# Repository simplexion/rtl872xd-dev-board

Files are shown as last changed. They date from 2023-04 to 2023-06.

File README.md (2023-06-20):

# RTL872xD Development Board
Development board(s) for the Realtek [RTL872xD](https://www.realtek.com/en/products/communications-network-ics/item/rtl8721dm) dual band WLAN and BLE MCU.
Please view the [product page](https://www.realmcu.com/en/Home/Product/a6248c82-7c9a-4f79-bebf-0df240726c4d) for detailed information and documentation.

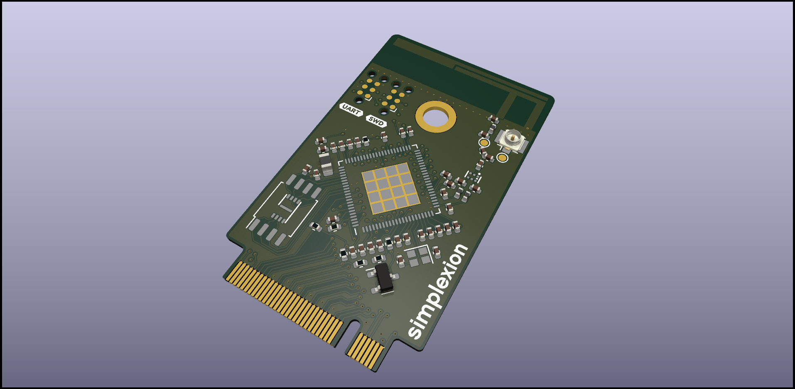
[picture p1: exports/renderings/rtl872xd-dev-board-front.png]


Browse the files on [KiCanvas](https://kicanvas.org/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) - by [Stargirl Flowers](https://github.com/theacodes)

## Directory Structure
| directory  | content |
|---|---|
| source | KiCad project directories |
| production | fabrication files (Gerber, BOM, placement) |
| exports | schematic and layout plots, board 3D model and renderings |
| datasheets | component datasheets |
| assets | board setups, component 3D models, logos |
| scripts | BOM export plugins, miscellaneous helper scripts for file conversion |
| hooks | git hooks, for example for automatic documentation export |

## Automation
This repository contains a Makefile that automates PDF and Gerber export.

### Requirements
Apart from [KiCad 7](#kicad-version) this requires some additional software.

The Makefile calls a Python script that makes use of [sexptdata](https://pypi.org/project/sexpdata/) to parse KiCad files.
Install [Poetry](https://python-poetry.org/) and run `poetry shell` followed by `poetry install` in the root of this repositoryto set up a virtual environment with the required package(s). To re-enter this environment, simply run `poetry shell` in the root of this repository.

For PDF export you additonally need to install [Poppler](https://poppler.freedesktop.org/).
Gerber export requires [zip](https://infozip.sourceforge.net/).

#### Nix(OS)
If you are using the Nix package manager, you can enter a development environment
with KiCad and all other software by running `nix-shell` in the root of this
repository.

### Export
To export all PDFs and production files, simply run
```shell
make
```
PDFs and production files are exported automatically when you `git commit`, if you have
[Git Hooks](#installing-git-hooks-optional) set up.

### Installing Git Hooks (optional)
The [hooks](hooks) directory contains client-side [git hooks](https://git-scm.com/book/en/v2/Customizing-Git-Git-Hooks).
Currently only the pre-commit hook is used to automatically export plots.

To enable the hooks locally, run the following in the root of the repository.
```shell
git config core.hooksPath ./hooks
```

## KiCad Version
Version information of the KiCad used to generate the files.
```
[nix-shell:~/repos/kicad-template]$ kicad-cli version --format about

Application: kicad-cli x86_64 on x86_64

Version: 7.0.1, release build

Libraries:
        wxWidgets 3.2.2
        FreeType 2.12.1
        HarfBuzz 6.0.0
        FontConfig 2.14.0
        libcurl/7.87.0 OpenSSL/3.0.8 zlib/1.2.13 brotli/1.0.9 zstd/1.5.2 libidn2/2.3.2 libssh2/1.10.0 nghttp2/1.51.0

Platform: , 64 bit, Little endian, wxBase, , wayland

Build Info:
        Date: Jan  1 1980 00:00:00
        wxWidgets: 3.2.2 (wchar_t,wx containers) GTK+ 0.0
        Boost: 1.79.0
        OCC: 7.6.2
        Curl: 7.87.0
        ngspice: 37
        Compiler: GCC 12.2.0 with C++ ABI 1017

Build settings:
        KICAD_USE_EGL=ON
        KICAD_SPICE=ON
```

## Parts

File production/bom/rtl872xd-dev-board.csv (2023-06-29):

Designator | Footprint | Quantity | Value | LCSC Part #
R3,R2 | Resistor_SMD:R_0402_1005Metric | 2 | 10k | C25744
R5 | Resistor_SMD:R_0402_1005Metric | 1 | 12k | C25752
J2 | Connector_M.2:M.2-B-KEY-22x | 1 | Bus_M.2_Socket_B
TP3,TP4,TP9,TP5,TP6,TP7,TP8 | TestPoint:TestPoint_Pad_D1.0mm | 7 | TestPoint
J3,J4 | Connector:Tag-Connect_TC2030-IDC-NL_2x03_P1.27mm_Vertical | 2 | Conn_ARM_SWD_TagConnect_TC2030-NL
C10,C17,C19,C20,C21,C22,C23,C24,C25,C26,C27,C28,C30,C32 | Capacitor_SMD:C_0402_1005Metric | 14 | 100n | C1525
U2 | Package_SO:SOIC-8_5.23x5.23mm_P1.27mm | 1 | W25Q128JVS | C97521
C13,C36 | Capacitor_SMD:C_0402_1005Metric | 2 | 1u | C52923
C14 | Capacitor_SMD:C_0402_1005Metric | 1 | 4.7n | C1538
C15,C29,C34,C35 | Capacitor_SMD:C_0402_1005Metric | 4 | 2.2u | C12530
C16 | Capacitor_SMD:C_0402_1005Metric | 1 | 10u | C15525
C18 | Capacitor_SMD:C_0402_1005Metric | 1 | 1n | C1523
C31 | Capacitor_SMD:C_0402_1005Metric | 1 | 4.7u | C23733
L4 | Inductor_SMD:L_0805_2012Metric | 1 | 2.2u | C1043
R6 | Resistor_SMD:R_0402_1005Metric | 1 | 200 | C25087
R7 | Resistor_SMD:R_0402_1005Metric | 1 | 1k | C25744
U4 | Package_TO_SOT_SMD:SOT-23 | 1 | LM809 | C526393
Y1 | Crystal:Crystal_SMD_2016-4Pin_2.0x1.6mm | 1 | 40MHz | C516561
AE1 | RF_Antenna_project:AKK_2.4GHz_5GHz_Left | 1 | Antenna_Shield
C1 | Capacitor_SMD:C_0402_1005Metric | 1 | 0.4p | C387964
C2 | Capacitor_SMD:C_0402_1005Metric | 1 | 0.3p | C610035
C3 | Capacitor_SMD:C_0402_1005Metric | 1 | 0.5p | C152789
C4 | Capacitor_SMD:C_0402_1005Metric | 1 | 1.0p | C1550
C5,C6 | Capacitor_SMD:C_0402_1005Metric | 2 | 0R | C17168
DP1 | RF_Diplexer:DP_0603_1608Metric | 1 | MDPX18M1524P69-D03 | C486317
J1 | Connector_Coaxial:U.FL_Hirose_U.FL-R-SMT-1_Vertical | 1 | Conn_Coaxial | C4749207
L1 | Inductor_SMD:L_0402_1005Metric | 1 | 1n | C74299
L2 | Inductor_SMD:L_0402_1005Metric | 1 | 3.3n | C280259
L3 | Inductor_SMD:L_0402_1005Metric | 1 | 1n(0.9n) | C74299
TP1,TP2 | TestPoint:TestPoint_Pad_D1.0mm | 2 | TestPoint

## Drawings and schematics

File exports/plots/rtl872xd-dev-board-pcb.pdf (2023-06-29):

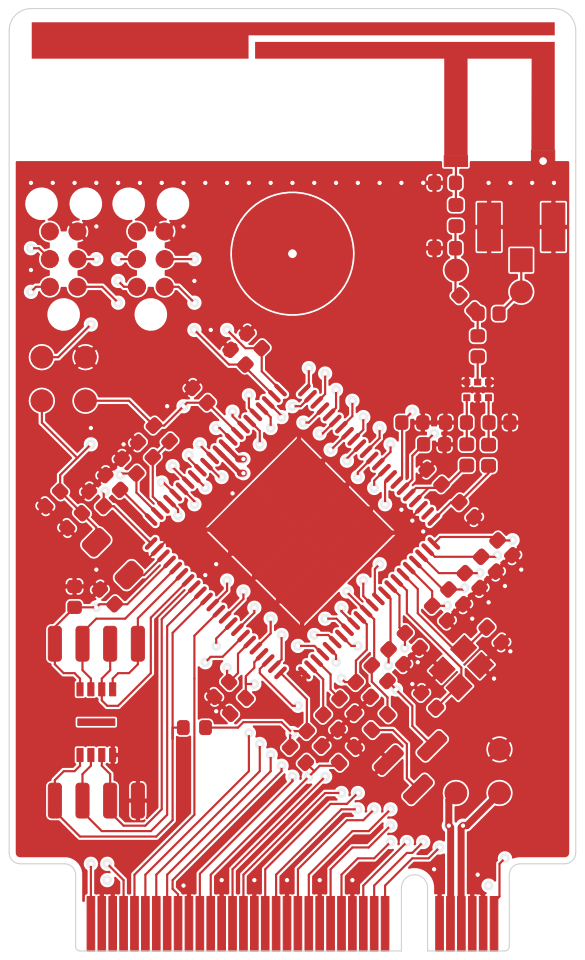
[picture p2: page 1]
D Date: KiCad; kicad-cli; 7.0.1 Size: A4; Rev: 0.1.0; author:; Markus "marble"; Blechschmidt pid: TBD

File: rtl872xd-dev-board.kicad_pcb Sheet: Simplexion GmbH

Id: 1/1 Title: RTL872xD Development Board

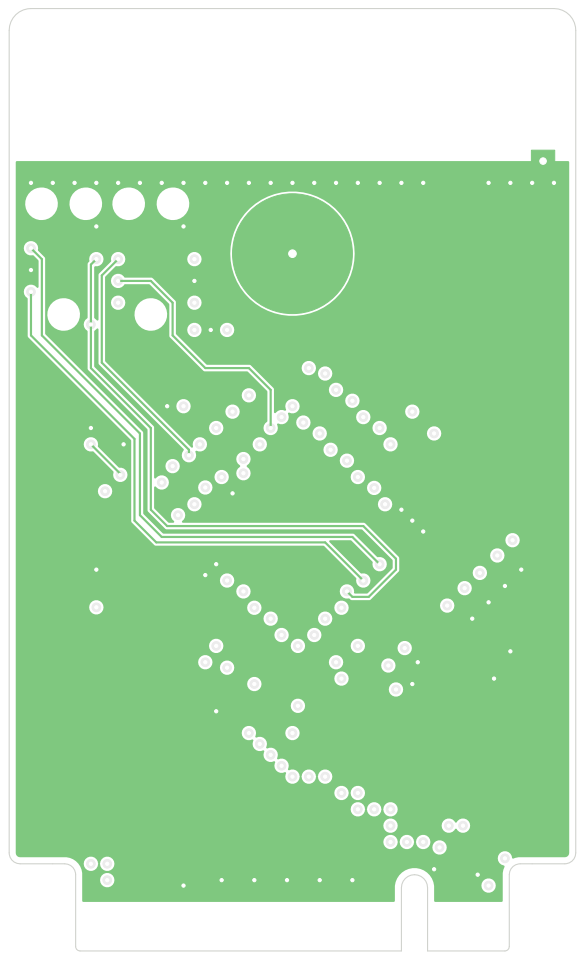
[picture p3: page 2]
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

File: rtl872xd-dev-board.kicad_pcb Sheet: Simplexion GmbH

Id: 1/1 Title: RTL872xD Development Board

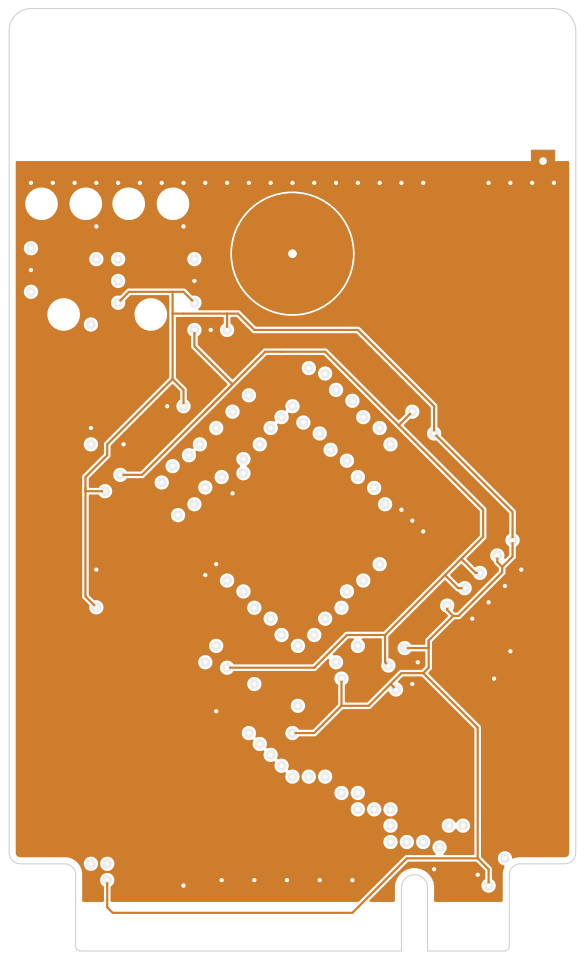
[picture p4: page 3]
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

File: rtl872xd-dev-board.kicad_pcb Sheet: Simplexion GmbH

Id: 1/1 Title: RTL872xD Development Board

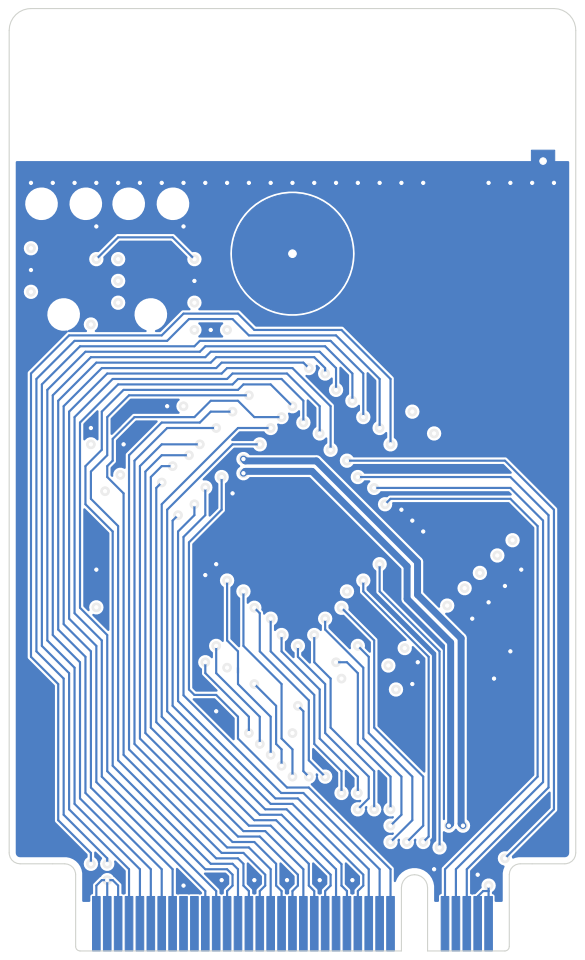
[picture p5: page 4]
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

File: rtl872xd-dev-board.kicad_pcb Sheet: Simplexion GmbH

Id: 1/1 Title: RTL872xD Development Board

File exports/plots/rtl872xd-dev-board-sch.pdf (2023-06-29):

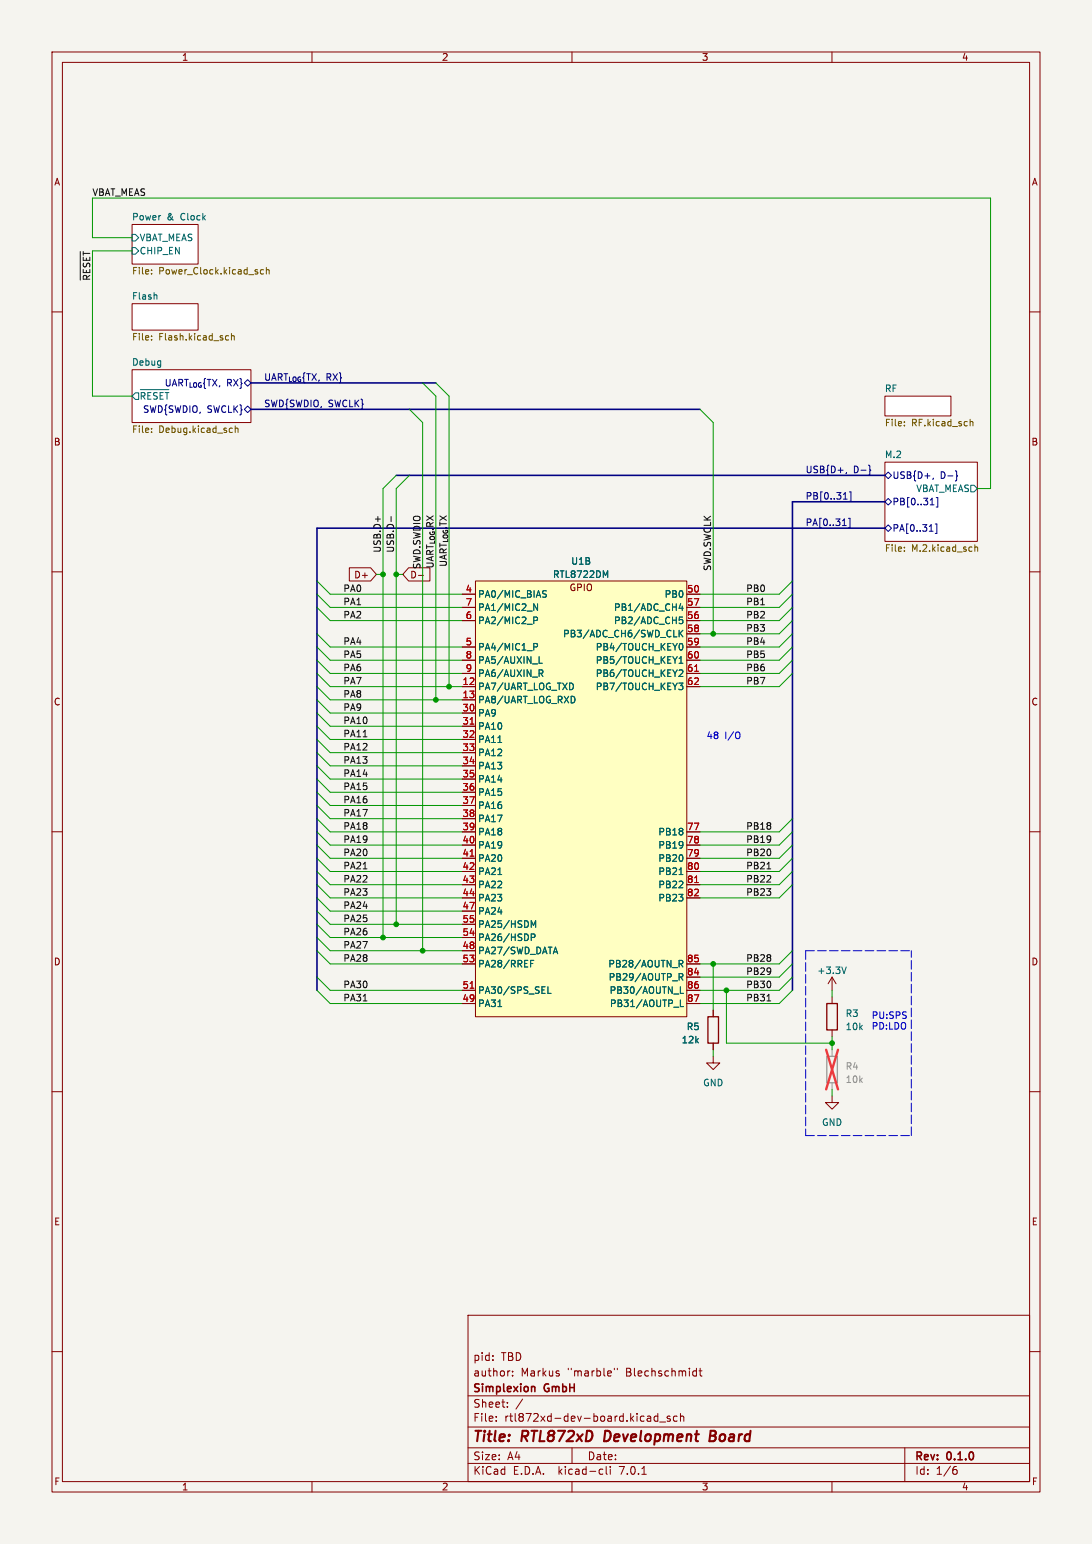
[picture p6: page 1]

USB{D+, D-} VBAT_MEAS M.2 File: M.2.kicad_sch Flash File: Flash.kicad_sch UART_{LOG}{TX, RX}

File: rtl872xd-dev-board.kicad_sch Sheet: / Simplexion GmbH

Id: 1/6 Title: RTL872xD Development Board

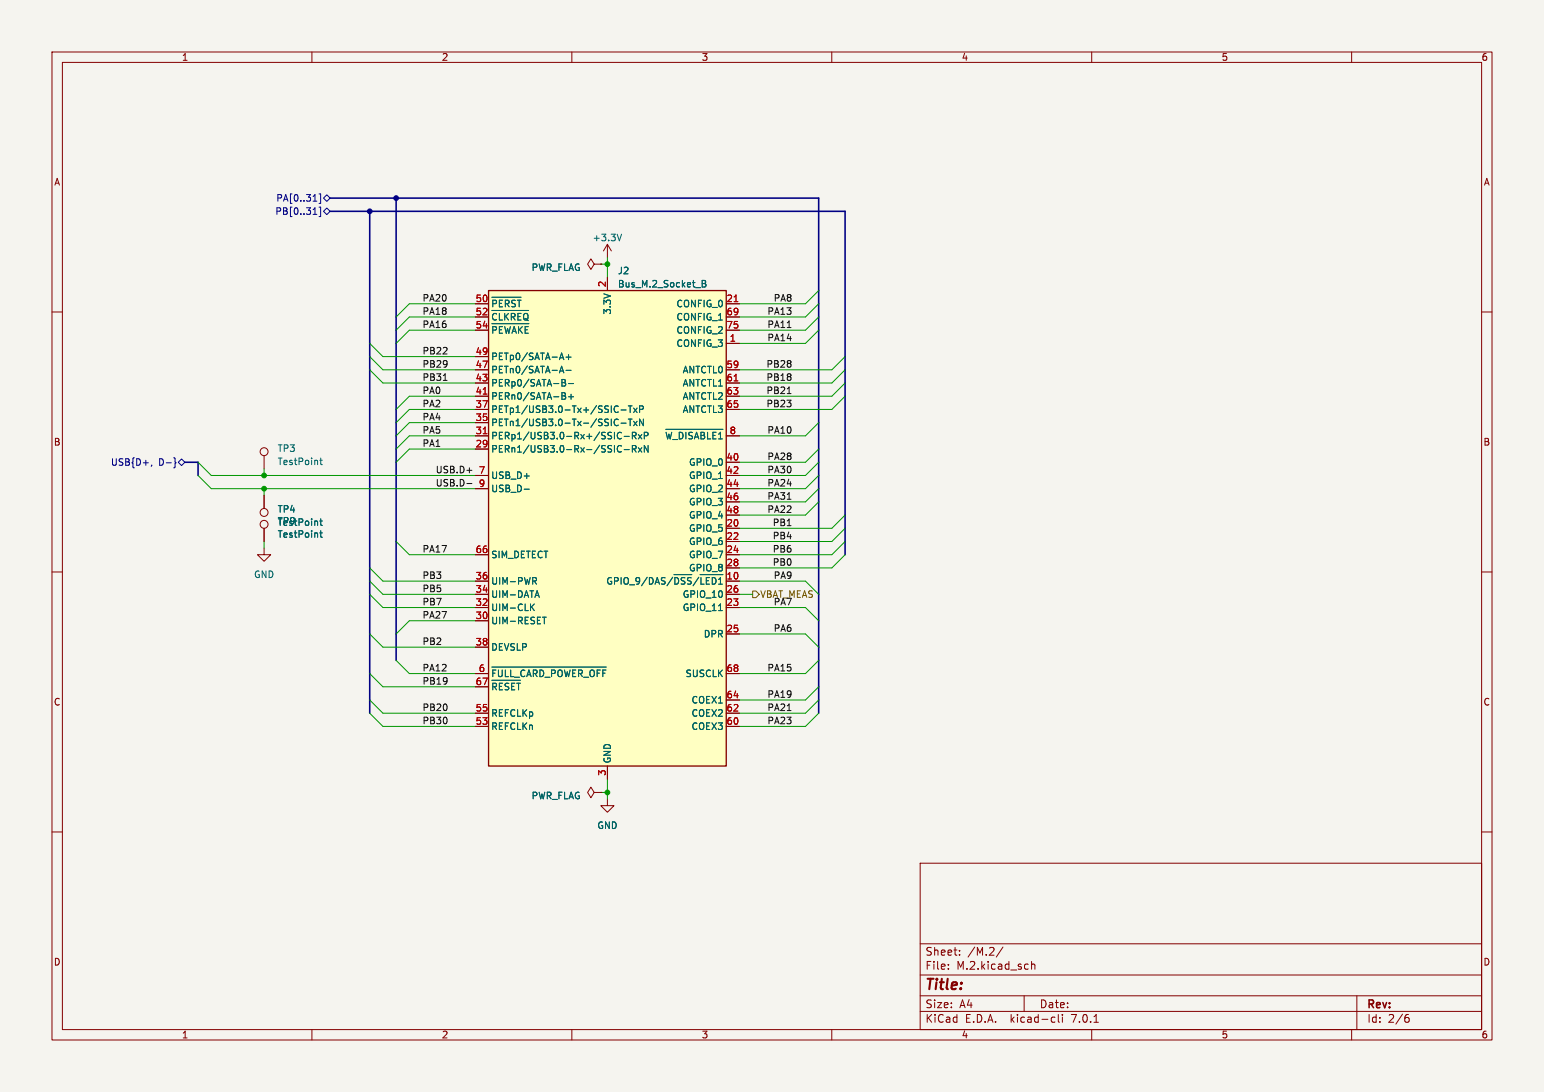
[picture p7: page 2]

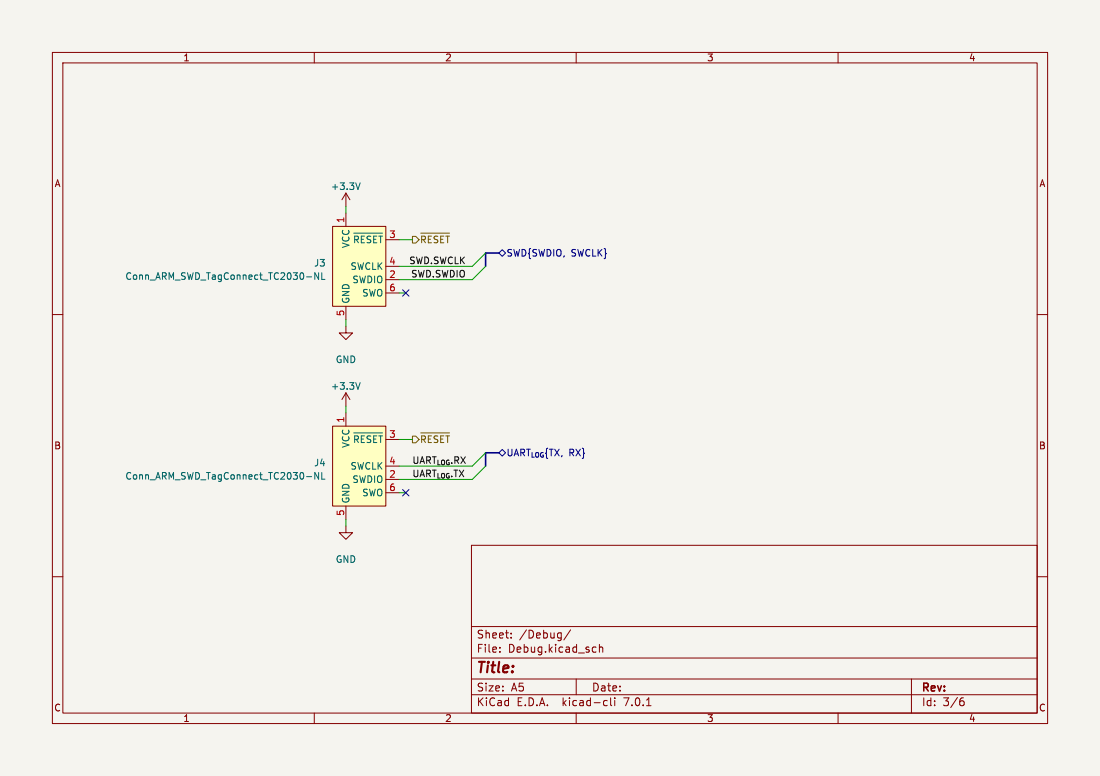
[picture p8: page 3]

1 SWDIO 2 ~{RESET}3 SWCLK 4 GND

~{RESET}
UART_{LOG}{TX, RX} UART_{LOG}.RX
UART_{LOG}.TX

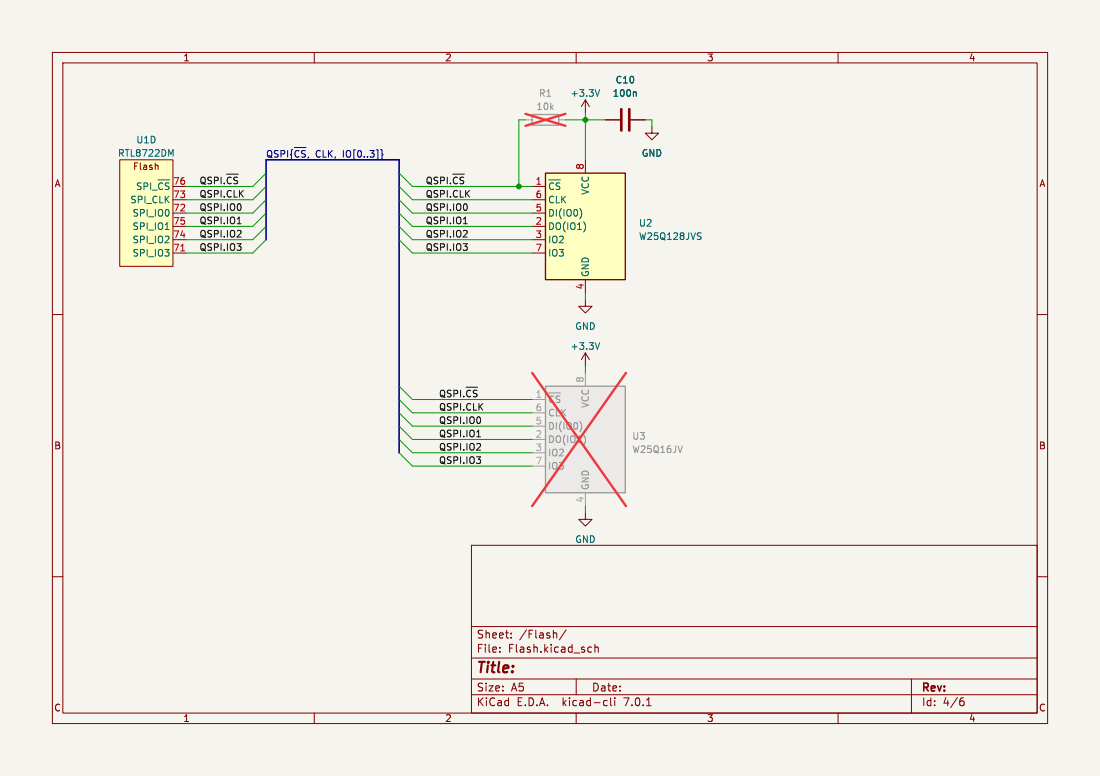
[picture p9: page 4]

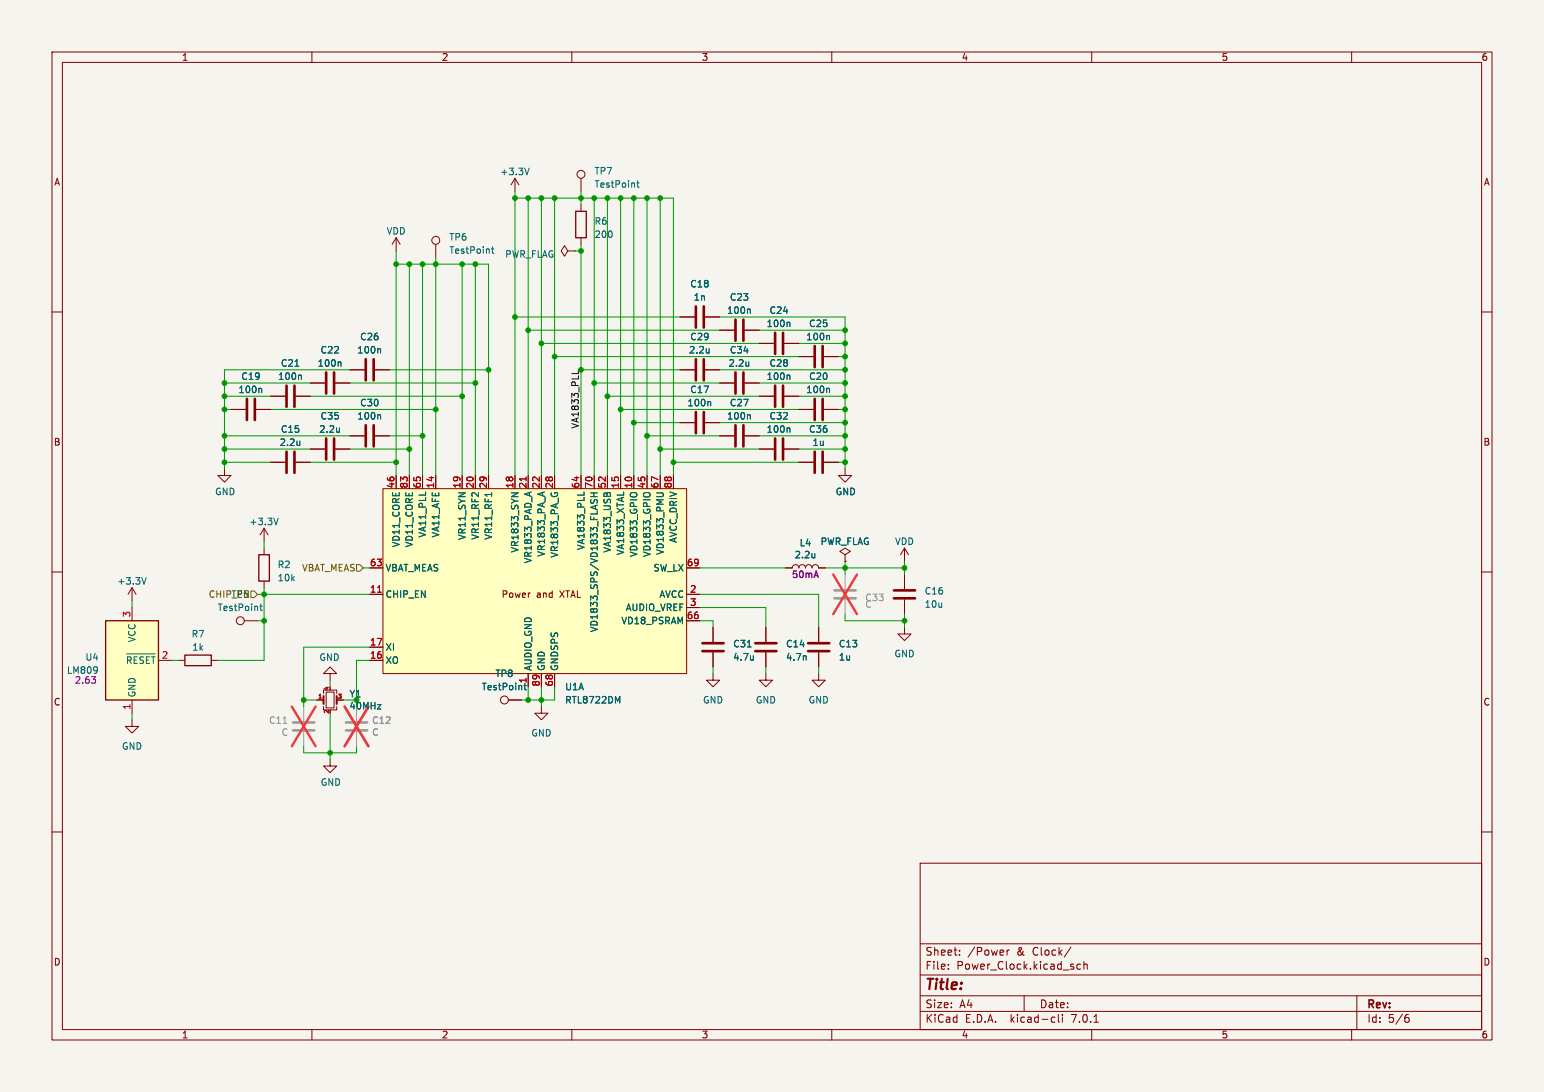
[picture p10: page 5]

1 VD1833_GPIO 10 VA11_AFE 14 VA1833_XTAL 15 XO 16 XI 17 VR1833_SYN 18 VR11_SYN 19 AVCC 2 VR11_RF2 20 VR1833_PAD_A 21 VR1833_PA_A 22 VR1833_PA_G 28 VR11_RF1 29 AUDIO_VREF 3 VD1833_GPIO 45 VD11_CORE 46 VA1833_USB 52 VBAT_MEAS 63 VA1833_PLL 64 VA11_PLL 65 VD18_PSRAM 66 VD1833_PMU 67 GNDSPS 68 SW_LX 69 VD1833_SPS/VD1833_FLASH 70 VD11_CORE 83 AVCC_DRIV 88 GND 89 U1A RTL8722DM

1 VD1833_GPIO 10 VA11_AFE 14 VA1833_XTAL 15 XO 16 XI 17 VR1833_SYN 18 VR11_SYN 19 AVCC 2 VR11_RF2 20 VR1833_PAD_A 21 VR1833_PA_A 22 VR1833_PA_G 28 VR11_RF1 29 AUDIO_VREF 3 VD1833_GPIO 45 VD11_CORE 46 VA1833_USB 52 VBAT_MEAS 63 VA1833_PLL 64 VA11_PLL 65 VD18_PSRAM 66 VD1833_PMU 67 GNDSPS 68 SW_LX 69 VD1833_SPS/VD1833_FLASH 70 VD11_CORE 83 AVCC_DRIV 88 GND 89 C12 C

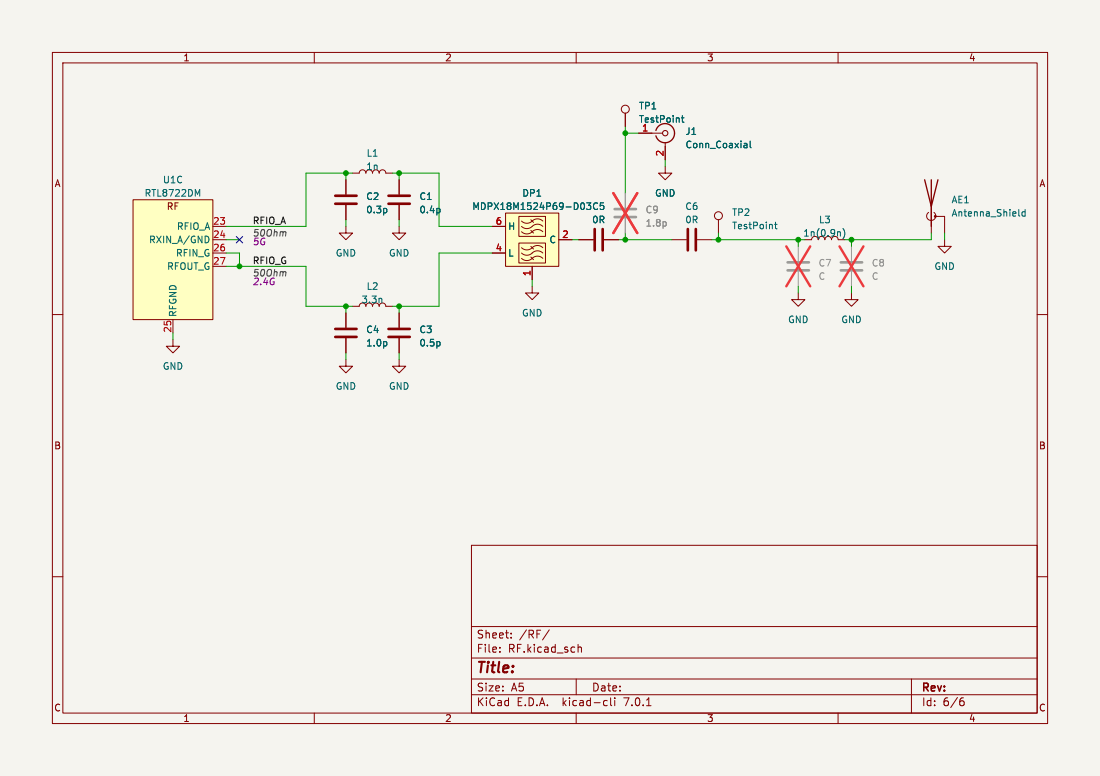
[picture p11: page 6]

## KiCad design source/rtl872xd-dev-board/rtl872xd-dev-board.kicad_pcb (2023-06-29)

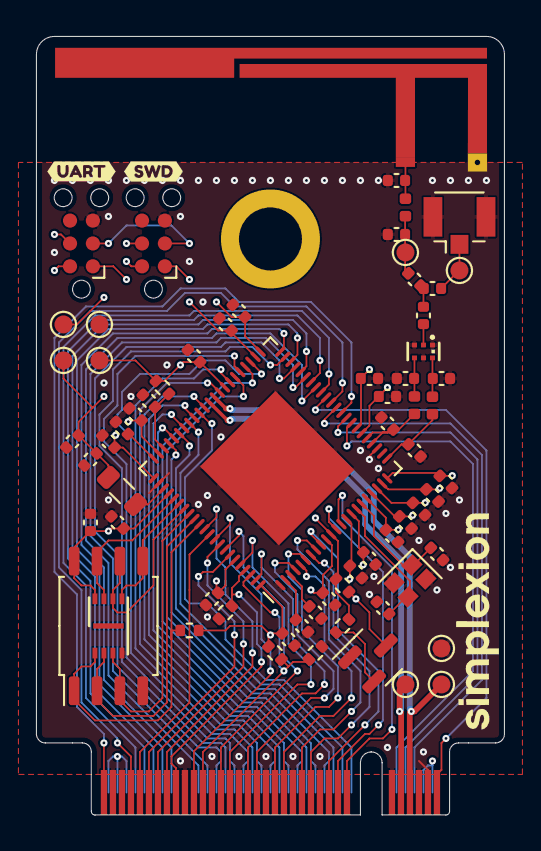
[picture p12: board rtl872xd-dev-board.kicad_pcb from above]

Board: 4 copper layers, 26.0 x 43.2 mm, 69 parts (0 on the bottom side), 76 nets.

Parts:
AE1: Antenna_Shield; AKK_2.4GHz_5GHz_Left
C1: 0.4p; C_0402_1005Metric
C2: 0.3p; C_0402_1005Metric
C3: 0.5p; C_0402_1005Metric
C4: 1.0p; C_0402_1005Metric
C5, C6: 0R; C_0402_1005Metric
C7, C8, C11, C12: C; C_0402_1005Metric
C9: 1.8p; C_0402_1005Metric
C10, C17, C19, C20, C21, C22, C23, C24, C25, C26, C27, C28, C30, C32: 100n; C_0402_1005Metric
C13, C36: 1u; C_0402_1005Metric
C14: 4.7n; C_0402_1005Metric
C15, C29, C34, C35: 2.2u; C_0402_1005Metric
C16: 10u; C_0402_1005Metric
C18: 1n; C_0402_1005Metric
C31: 4.7u; C_0402_1005Metric
C33: C_0402_1005Metric
DP1: MDPX18M1524P69-D03; DP_0603_1608Metric
J1: Conn_Coaxial; U.FL_Hirose_U.FL-R-SMT-1_Vertical
J2: Bus_M.2_Socket_B; M.2-B-KEY-22x
J3, J4: Conn_ARM_SWD_TagConnect_TC2030-NL; Tag-Connect_TC2030-IDC-NL_2x03_P1.27mm_Vertical
L1: 1n; L_0402_1005Metric
L2: 3.3n; L_0402_1005Metric
L3: L; L_0402_1005Metric
L4: 2.2u; L_0805_2012Metric
R1, R2, R3, R4: 10k; R_0402_1005Metric
R5: 12k; R_0402_1005Metric
R6: 200; R_0402_1005Metric
R7: 1k; R_0402_1005Metric
TP1, TP2, TP3, TP4, TP5, TP6, TP7, TP8, TP9: TestPoint; TestPoint_Pad_D1.0mm
U1: RTL8722DM; QFN-88_EP_10x10_Pitch0.4mm
U2: W25Q128JVS; SOIC-8_5.23x5.23mm_P1.27mm
U3: W25Q16JV; USON-8_3.0x2.0mm_P0.5mm
U4: LM809; SOT-23
Y1: 40MHz; Crystal_SMD_2016-4Pin_2.0x1.6mm
kibuzzard-6492E3AE: G***; kibuzzard-6492E3AE
kibuzzard-6492E3B2: G***; kibuzzard-6492E3B2

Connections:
+3.3V: C10.1, C17.2, C18.2, C20.2, C23.2, C24.2, C25.2, C27.2, C28.2, C32.2, C34.2, C36.2, J2.2 (3.3V), J2.4 (3.3V), J2.70 (3.3V), J2.72 (3.3V), J2.74 (3.3V), J3.1 (VCC), J4.1 (VCC), R1.2, R2.1, R3.2, R6.1, TP7.1, U1.10 (VD1833_GPIO), U1.15 (VA1833_XTAL), U1.18 (VR1833_SYN), U1.21 (VR1833_PAD_A), U1.22 (VR1833_PA_A), U1.28 (VR1833_PA_G), U1.45 (VD1833_GPIO), U1.52 (VA1833_USB), U1.67 (VD1833_PMU), U1.70 (VD1833_SPS/VD1833_FLASH), U1.88 (AVCC_DRIV), U2.8 (VCC), U3.8 (VCC), U4.3 (VCC)
/Flash/QSPI.CLK: U1.73 (SPI_CLK), U2.6 (CLK), U3.6 (CLK)
/Flash/QSPI.IO0: U1.72 (SPI_IO0), U2.5 (DI(IO0)), U3.5 (DI(IO0))
/Flash/QSPI.IO1: U1.75 (SPI_IO1), U2.2 (DO(IO1)), U3.2 (DO(IO1))
/Flash/QSPI.IO2: U1.74 (SPI_IO2), U2.3 (IO2), U3.3 (IO2)
/Flash/QSPI.IO3: U1.71 (SPI_IO3), U2.7 (IO3), U3.7 (IO3)
/Flash/QSPI.~CS: R1.1, U1.76 (SPI_~CS), U2.1 (~CS), U3.1 (~CS)
/PA0: J2.41 (PERn0/SATA-B+), U1.4 (PA0/MIC_BIAS)
/PA1: J2.29 (PERn1/USB3.0-Rx-/SSIC-RxN), U1.7 (PA1/MIC2_N)
/PA2: J2.37 (PETp1/USB3.0-Tx+/SSIC-TxP), U1.6 (PA2/MIC2_P)
/PA4: J2.35 (PETn1/USB3.0-Tx-/SSIC-TxN), U1.5 (PA4/MIC1_P)
/PA5: J2.31 (PERp1/USB3.0-Rx+/SSIC-RxP), U1.8 (PA5/AUXIN_L)
/PA6: J2.25 (DPR), U1.9 (PA6/AUXIN_R)
/PA9: J2.10 (GPIO_9/DAS/~DSS/~LED1), U1.30 (PA9)
/PA10: J2.8 (~W_DISABLE1), U1.31 (PA10)
/PA11: J2.75 (CONFIG_2), U1.32 (PA11)
/PA12: J2.6 (~FULL_CARD_POWER_OFF), U1.33 (PA12)
/PA13: J2.69 (CONFIG_1), U1.34 (PA13)
/PA14: J2.1 (CONFIG_3), U1.35 (PA14)
/PA15: J2.68 (SUSCLK), U1.36 (PA15)
/PA16: J2.54 (~PEWAKE), U1.37 (PA16)
/PA17: J2.66 (SIM_DETECT), U1.38 (PA17)
/PA18: J2.52 (~CLKREQ), U1.39 (PA18)
/PA19: J2.64 (COEX1), U1.40 (PA19)
/PA20: J2.50 (~PERST), U1.41 (PA20)
/PA21: J2.62 (COEX2), U1.42 (PA21)
/PA22: J2.48 (GPIO_4), U1.43 (PA22)
/PA23: J2.60 (COEX3), U1.44 (PA23)
/PA24: J2.44 (GPIO_2), U1.47 (PA24)
/PA28: J2.40 (GPIO_0), U1.53 (PA28/RREF)
/PA30: J2.42 (GPIO_1), U1.51 (PA30/SPS_SEL)
/PA31: J2.46 (GPIO_3), U1.49 (PA31)
/PB0: J2.28 (GPIO_8), U1.50 (PB0)
/PB1: J2.20 (GPIO_5), U1.57 (PB1/ADC_CH4)
/PB2: J2.38 (DEVSLP), U1.56 (PB2/ADC_CH5)
/PB4: J2.22 (GPIO_6), U1.59 (PB4/TOUCH_KEY0)
/PB5: J2.34 (UIM-DATA), U1.60 (PB5/TOUCH_KEY1)
/PB6: J2.24 (GPIO_7), U1.61 (PB6/TOUCH_KEY2)
/PB7: J2.32 (UIM-CLK), U1.62 (PB7/TOUCH_KEY3)
/PB18: J2.61 (ANTCTL1), U1.77 (PB18)
/PB19: J2.67 (~RESET), U1.78 (PB19)
/PB20: J2.55 (REFCLKp), U1.79 (PB20)
/PB21: J2.63 (ANTCTL2), U1.80 (PB21)
/PB22: J2.49 (PETp0/SATA-A+), U1.81 (PB22)
/PB23: J2.65 (ANTCTL3), U1.82 (PB23)
/PB28: J2.59 (ANTCTL0), R5.2, U1.85 (PB28/AOUTN_R)
/PB29: J2.47 (PETn0/SATA-A-), U1.84 (PB29/AOUTP_R)
/PB30: J2.53 (REFCLKn), R3.1, R4.2, U1.86 (PB30/AOUTN_L)
/PB31: J2.43 (PERp0/SATA-B-), U1.87 (PB31/AOUTP_L)
/Power & Clock/VA1833_PLL: C29.2, R6.2, U1.64 (VA1833_PLL)
/RF/RFIO_A: C2.1, L1.1, U1.23 (RFIO_A)
/RF/RFIO_G: C4.1, L2.1, U1.26 (RFIN_G), U1.27 (RFOUT_G)
/SWD.SWCLK: J2.36 (UIM-PWR), J3.4 (SWCLK), U1.58 (PB3/ADC_CH6/SWD_CLK)
/SWD.SWDIO: J2.30 (UIM-RESET), J3.2 (SWDIO), U1.48 (PA27/SWD_DATA)
/UART_{LOG}.RX: J2.21 (CONFIG_0), J4.4 (SWCLK), U1.13 (PA8/UART_LOG_RXD)
/UART_{LOG}.TX: J2.23 (GPIO_11), J4.2 (SWDIO), U1.12 (PA7/UART_LOG_TXD)
/VBAT_MEAS: J2.26 (GPIO_10), U1.63 (VBAT_MEAS)
/~RESET: J3.3 (~RESET), J4.3 (~RESET), R2.2, R7.2, TP5.1, U1.11 (CHIP_EN)
D+: J2.7 (USB_D+), TP3.1, U1.54 (PA26/HSDP)
D-: J2.9 (USB_D-), TP4.1, U1.55 (PA25/HSDM)
GND: AE1.2 (Shield), C1.2, C2.2, C3.2, C4.2, C7.2, C8.2, C10.2, C11.2, C12.2, C13.1, C14.1, C15.2, C16.1, C17.1, C18.1, C19.2, C20.1, C21.2, C22.2, C23.1, C24.1, C25.1, C26.2, C27.1, C28.1, C29.1, C30.2, C31.1, C32.1, C33.1, C34.1, C35.2, C36.1, DP1.1, DP1.3 (GND), DP1.5 (GND), J1.2 (Ext), J2.3 (GND), J2.5 (GND), J2.11 (GND), J2.27 (GND), J2.33 (GND), J2.39 (GND), J2.45 (GND), J2.51 (GND), J2.57 (GND), J2.71 (GND), J2.73 (GND), J3.5 (GND), J4.5 (GND), R4.1, R5.1, TP8.1, TP9.1, U1.1 (AUDIO_GND), U1.25 (RFGND), U1.68 (GNDSPS), U1.89 (GND), U2.4 (GND), U3.4 (GND), U4.1 (GND), Y1.2, Y1.4
unnamed: AE1.1 (A), C8.1, L3.2
unnamed: C5.2, C6.1, C9.1
unnamed: C6.2, C7.1, L3.1, TP2.1
unnamed: C5.1, DP1.2 (C)
unnamed: C1.1, DP1.6 (H), L1.2
unnamed: C3.1, DP1.4 (L), L2.2
unnamed: C9.2, J1.1 (In), TP1.1
unnamed: C14.2, U1.3 (AUDIO_VREF)
unnamed: C13.2, U1.2 (AVCC)
unnamed: L4.1, U1.69 (SW_LX)
unnamed: C31.2, U1.66 (VD18_PSRAM)
unnamed: C11.1, U1.17 (XI), Y1.1
unnamed: C12.1, U1.16 (XO), Y1.3
unnamed: R7.1, U4.2 (~RESET)
VDD: C15.1, C16.2, C19.1, C21.1, C22.1, C26.1, C30.1, C33.2, C35.1, L4.2, TP6.1, U1.14 (VA11_AFE), U1.19 (VR11_SYN), U1.20 (VR11_RF2), U1.29 (VR11_RF1), U1.46 (VD11_CORE), U1.65 (VA11_PLL), U1.83 (VD11_CORE)

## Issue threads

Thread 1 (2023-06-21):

style decision: add units to passives?

simplexion-hanebeck, 2023-06-21:
I suggest adding units to the passive components, for example
| part | now |  suggestion |
| --- | --- | --- |
| L4 | 2.2u  | 2.2uH |
| C13 | 1u | 1uF |
| R2 | 10k | 10kR or 10kΩ |

advantages:
- clearer component description
- reduces risk of selecting wrong component type while ordering

disadvantages:
- "noisier" schematics and placement plots

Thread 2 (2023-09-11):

Adapt LN60 pin assignments

simplexion-blechschmidt, 2023-09-11:
Maybe adapt LN60 pin assignments (power, signal, debug) for compatibility.

simplexion-blechschmidt, 2023-09-11:
https://www.mouser.de/datasheet/2/915/Fanstel_11192020_LN60-1923896.pdf#page=14

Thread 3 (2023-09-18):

Route RTL8722 ~RESET to M.2 pin 67 (M.2 ~RESET)

simplexion-hanebeck, 2023-09-18:
There's no RESET on the M.2 connector. For easier flashing, the RESET line would be nice at the M.2 reset pin.

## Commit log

2023-04-28 Initial commit for rtl872xd-dev-board
    [rtl872xd-dev-board.kicad_pcb, rtl872xd-dev-board.kicad_sch]
2023-06-20 finished prelim layout
    [Flash.kicad_sch, M.2.kicad_sch, Power_Clock.kicad_sch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]
2023-06-21 added TC2030 debug ports
    [rtl872xd-dev-board-B.Cu.gbr, rtl872xd-dev-board-B.Mask.gbr, rtl872xd-dev-board-B.Paste.gbr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]
2023-06-21 remove unused schematic
    [M.2.kicad_sch]
2023-06-21 resolve all ERC error, reduce number of warnings
    [Flash.kicad_sch, Power_Clock.kicad_sch, RF.kicad_sch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]
2023-06-21 tidied up like Marie Kondo
    [Debug.kicad_sch, Flash.kicad_sch, M.2.kicad_sch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]
2023-06-29 first production version
    [Flash.kicad_sch, M.2.kicad_sch, Power_Clock.kicad_sch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]
